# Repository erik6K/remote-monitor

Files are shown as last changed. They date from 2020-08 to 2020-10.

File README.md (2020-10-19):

# Repeater Monitor
## Background
An IoT device has been created to monitor the 240V AC normal supply, and 12V DC battery back-up supply for a radio repeater. Refer to the Project Design and Testing Document submitted along with this git repository for more information. The purpose of this git repository is to:
* Store the Arduino firmware backups for deploying new devices, or adding functionality
* Store relevent hardware manuals

To facilitate continuous deployment of the web application, it has been moved to a separate git repository. Updates to the web application should be made within this repository: [Repeater Monitor Web Application](https://github.com/tarrantja/remote-monitor-web). Updates made to the web application contained within this repository will not be deployed. 

## Authors
Created by:
* **Rio Akbar** (22507035)
* **Calvin Nguyen** (22509815)
* **Erik Stefan** (22224939)
* **James Tarrant** (20924309)
* **Dylan Turner** (22240231)

Developed for use in CITS3200, on behalf of SES CSU. 
[The full git repository can be found here.](https://github.com/tarrantja/remote-monitor-web)

## Licences
Hardware: CC BY-NC 3.0 AU

Firmware: GPLv3

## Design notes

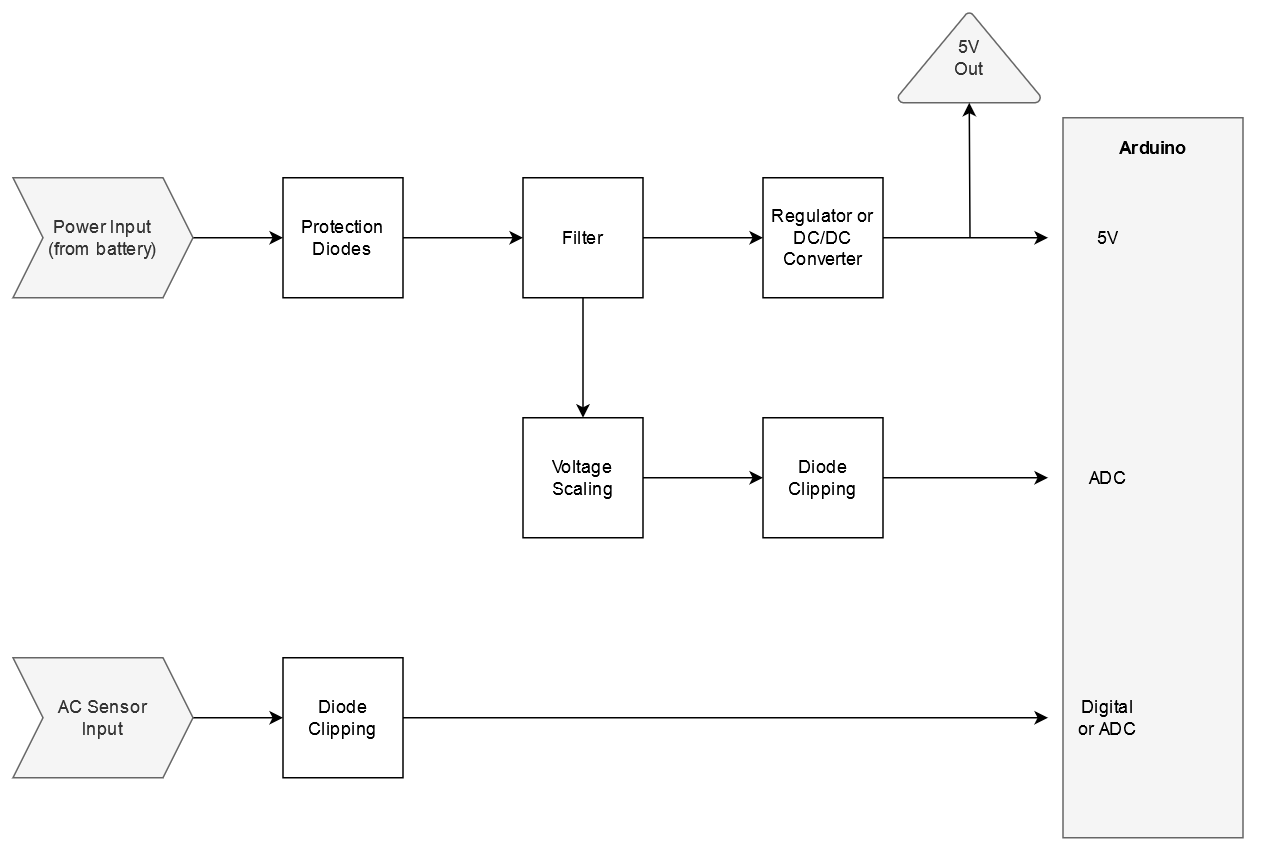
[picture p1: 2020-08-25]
hardware/Block Diagram.png

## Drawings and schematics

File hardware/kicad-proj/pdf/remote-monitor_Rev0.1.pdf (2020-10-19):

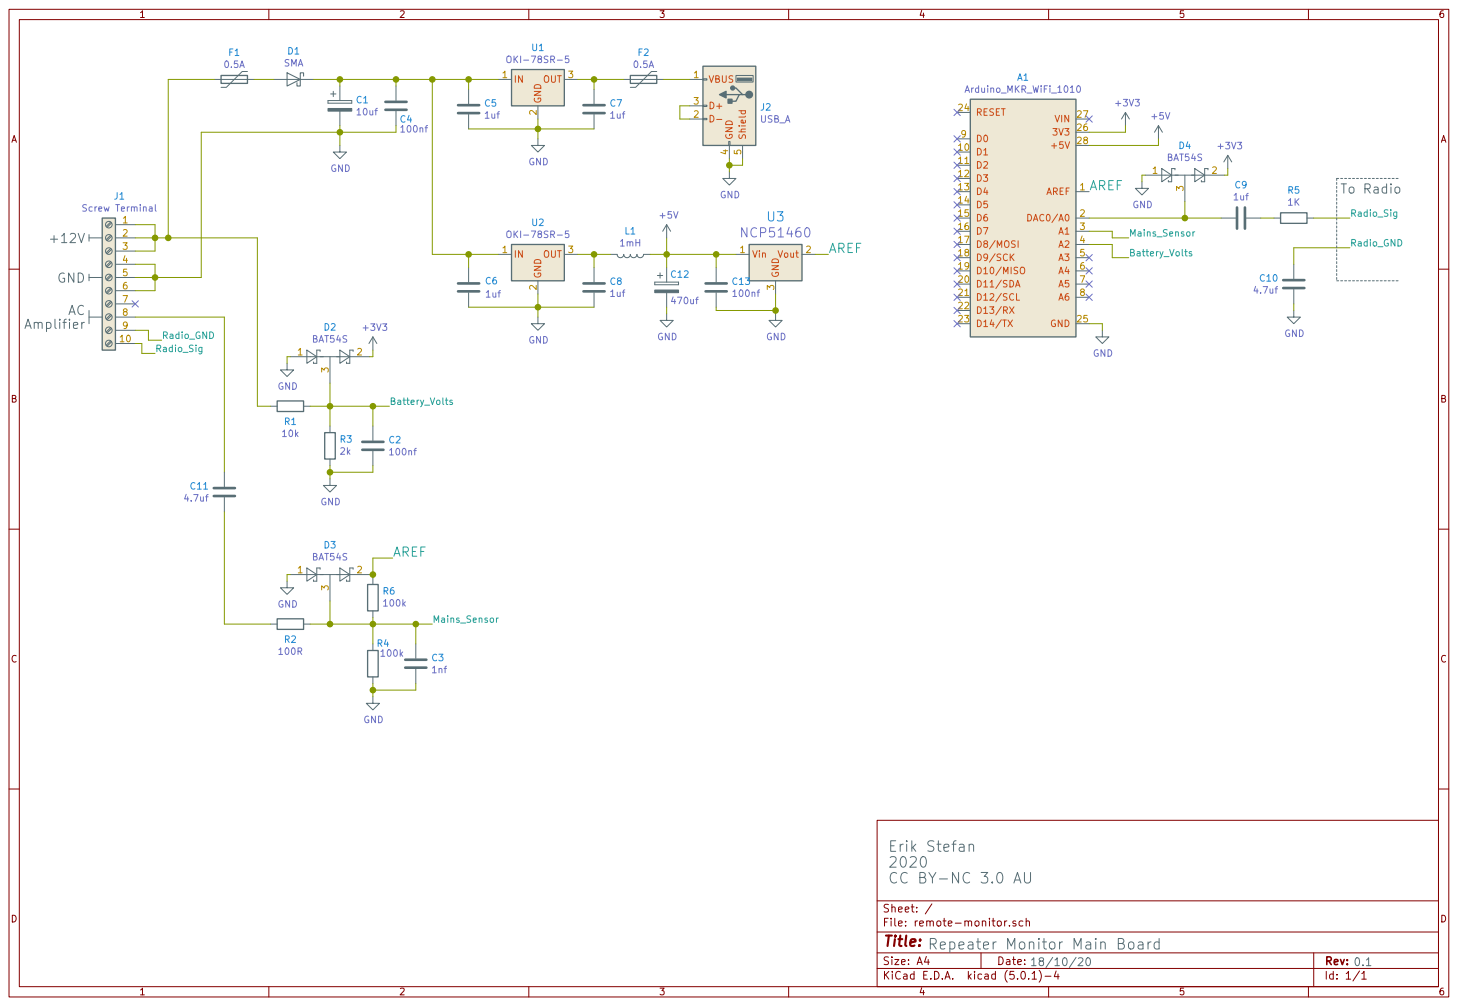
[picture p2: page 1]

Erik Stefan

Id: 1/1 Title: File: remote-monitor.sch Sheet: /
0.1 Repeater Monitor Main Board

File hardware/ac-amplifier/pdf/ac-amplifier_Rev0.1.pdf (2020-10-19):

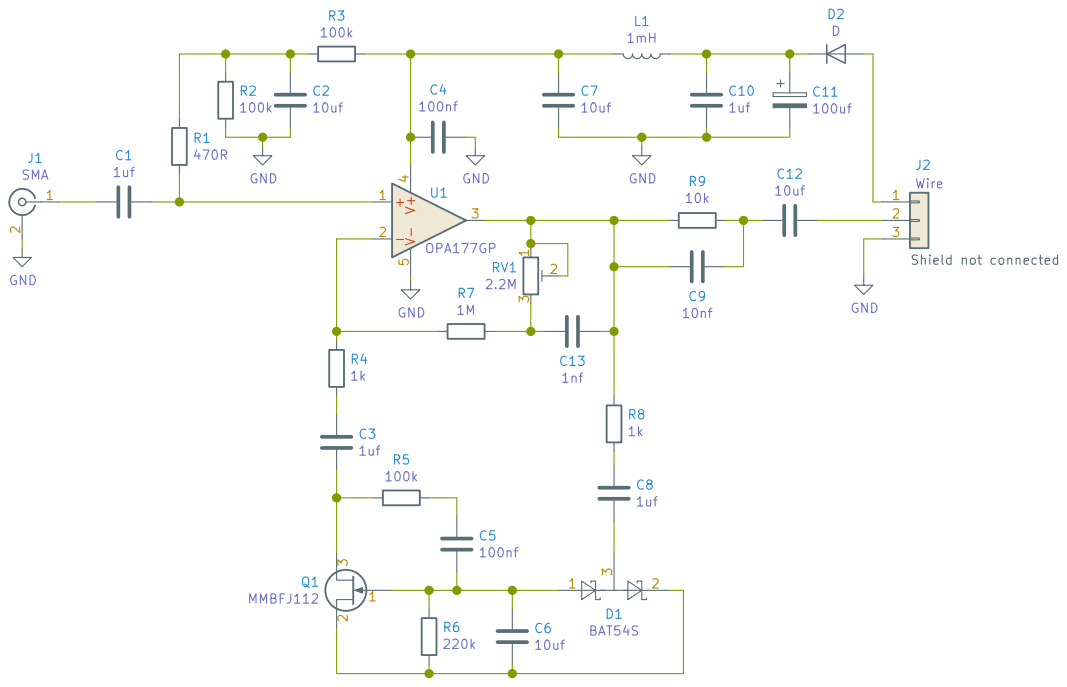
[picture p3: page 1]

Erik Stefan

File: ac-amplifier.sch Sheet: /
Id: 1/1 Title:
0.1 Repeater Monitor AC Amplifier

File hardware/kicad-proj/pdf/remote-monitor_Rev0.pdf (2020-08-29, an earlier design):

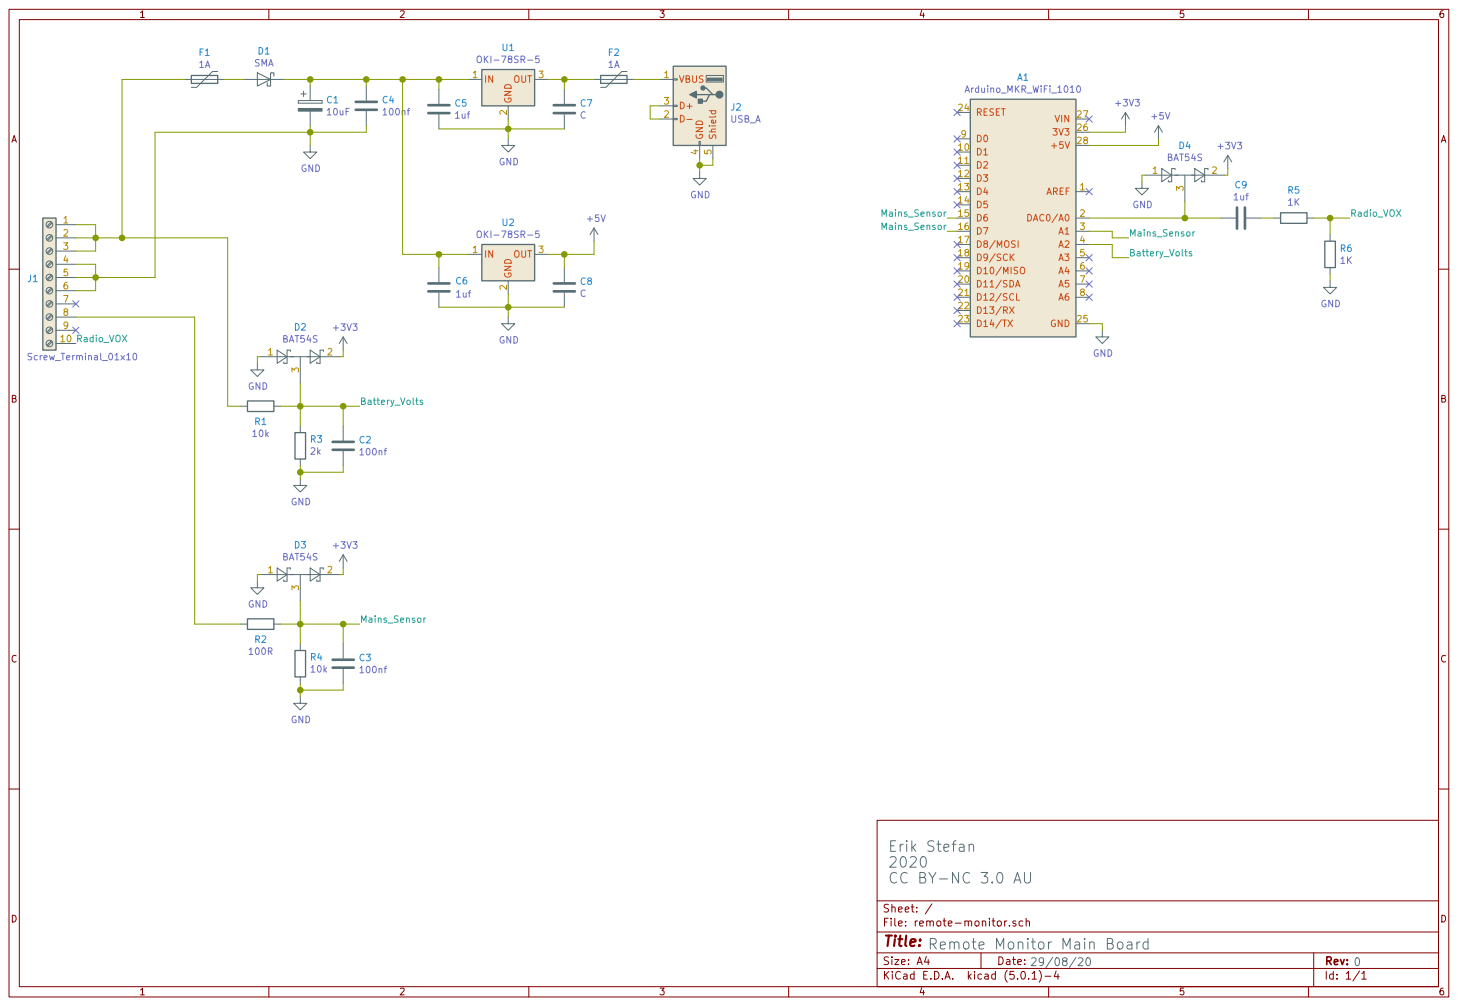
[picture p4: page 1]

Erik Stefan

Id: 1/1 Title: File: remote-monitor.sch Sheet: /
0 Remote Monitor Main Board

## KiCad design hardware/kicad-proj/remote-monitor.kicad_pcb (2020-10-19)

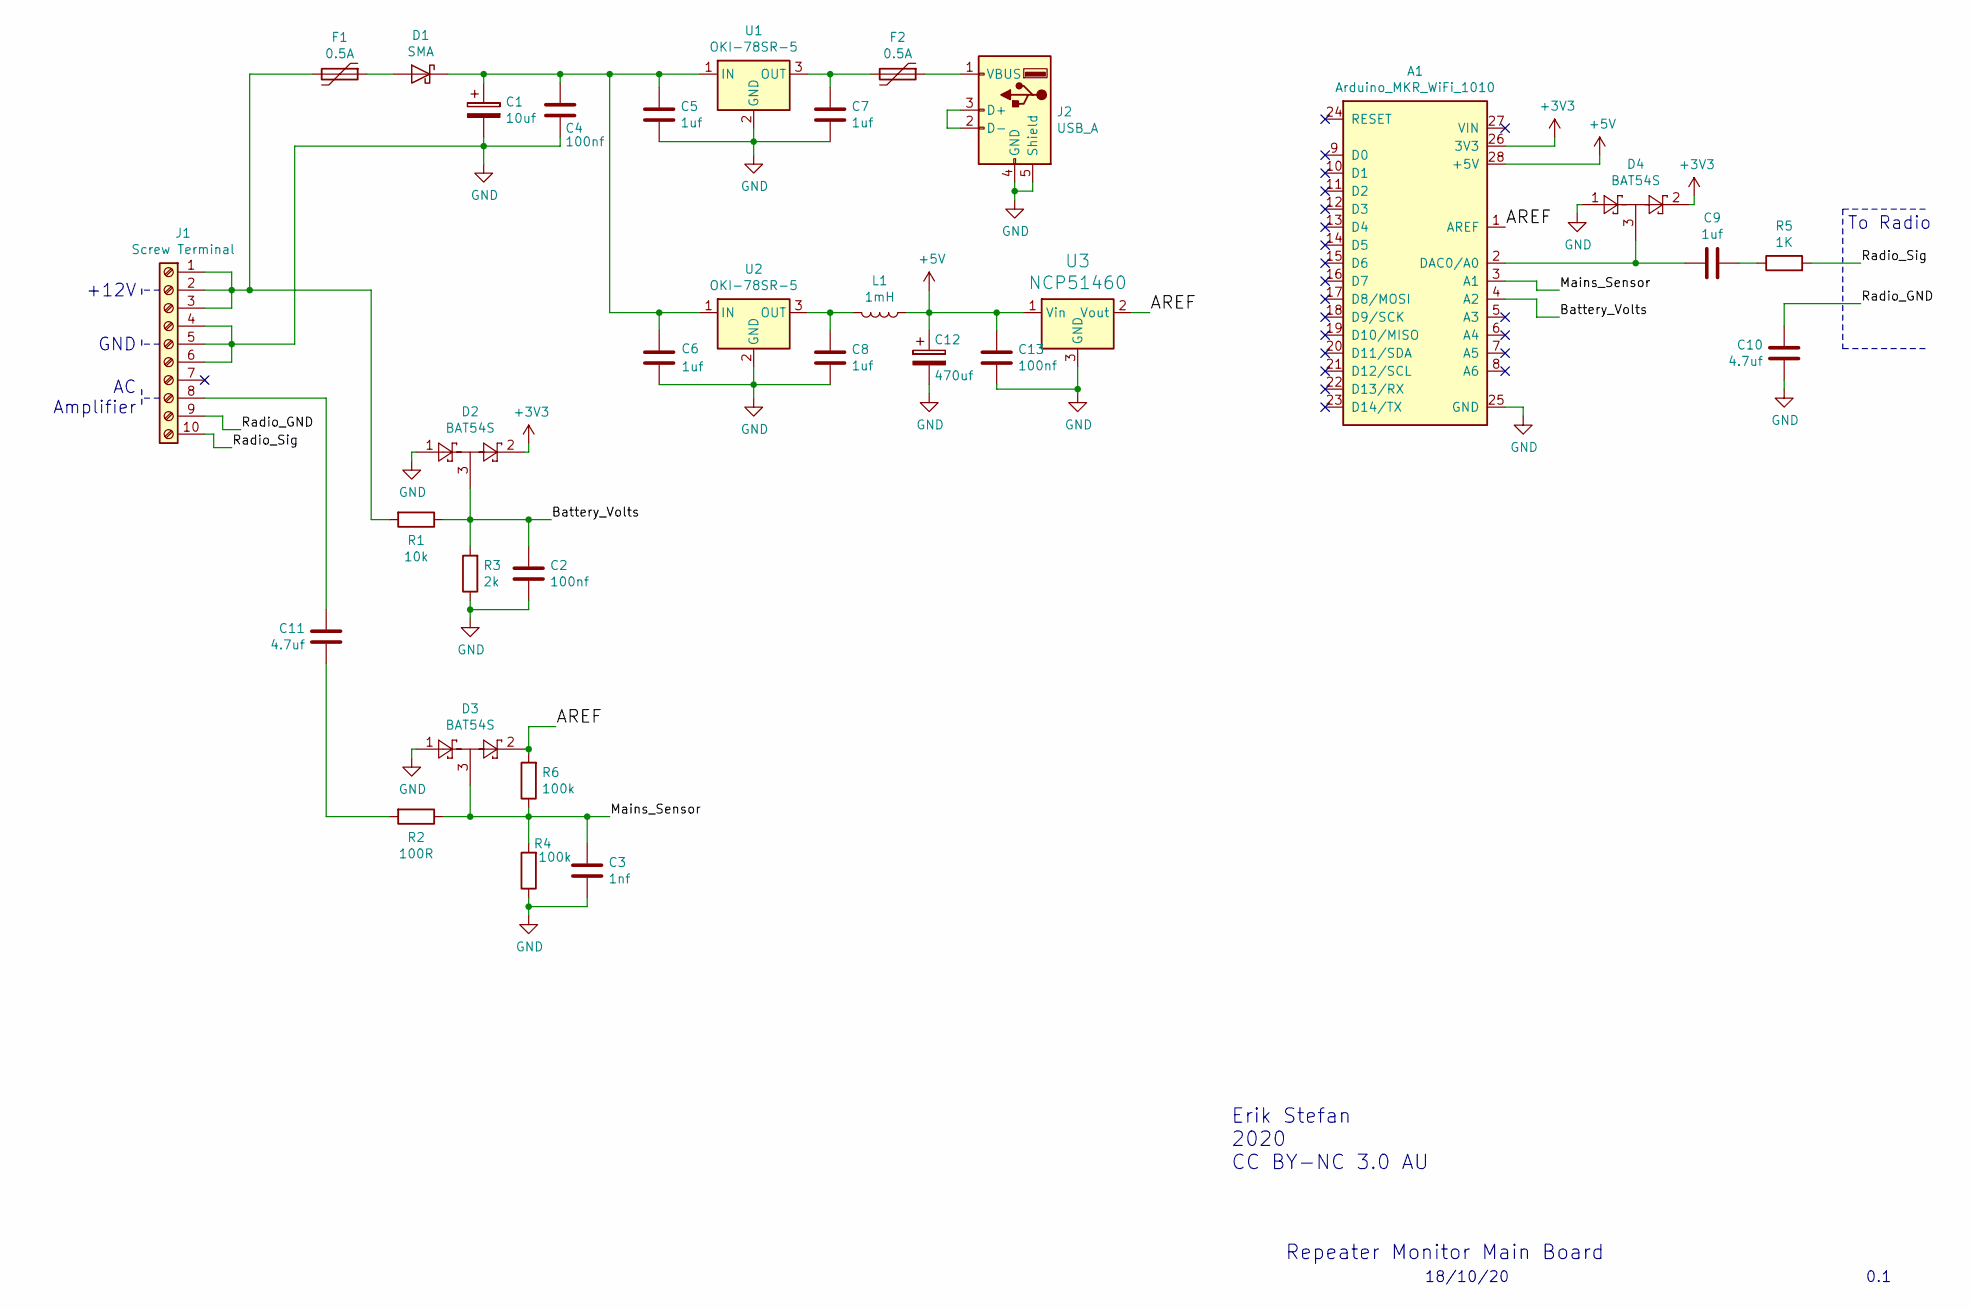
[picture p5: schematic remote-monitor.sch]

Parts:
A1: Arduino_MKR_WiFi_1010; Arduino_MKR_1010
C1: 10uf; CP_Elec_5x4.5
C2, C4, C13: 100nf; C_1206_3216Metric
C3: 1nf; C_1206_3216Metric
C5, C6, C7, C8, C9: 1uf; C_1206_3216Metric
C10, C11: 4.7uf; C_1206_3216Metric
C12: 470uf; CP_Elec_8x10.5
D1: SMA; D_SMA
D2, D3, D4: BAT54S; SOT-23
F1, F2: 0.5A; Fuse_1812_4532Metric
J1: Screw Terminal; Screw_Terminal_1x10
J2: USB_A; USB_A_Molex_105057_Vertical
L1: 1mH; L_6.3x6.3_H3
R1: 10k; R_1206_3216Metric
R2: 100R; R_1206_3216Metric
R3: 2k; R_1206_3216Metric
R4, R6: 100k; R_1206_3216Metric
R5: 1K; R_1206_3216Metric
U1, U2: OKI-78SR-5; Converter_DCDC_muRata_OKI-78SR_Vertical
U3: NCP51460; SOT-23

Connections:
+3V3: A1.26 (3V3), D2.2, D4.2
+5V: A1.28 (+5V), C12.1, C13.1, L1.1, U3.1 (Vin)
/AREF: A1.1 (AREF), D3.2, R6.2, U3.2 (Vout)
/Battery_Volts: A1.4 (A2), C2.1, D2.3, R1.1, R3.2
/Mains_Sensor: A1.3 (A1), C3.1, D3.3, R2.1, R4.2, R6.1
/Radio_GND: C10.1, J1.9
/Radio_Sig: J1.10, R5.2
GND: A1.25 (GND), C1.2, C2.2, C3.2, C4.2, C5.2, C6.2, C7.2, C8.2, C10.2, C12.2, C13.2, D2.1, D3.1, D4.1, J1.4, J1.5, J1.6, J2.4 (GND), J2.5 (Shield), R3.1, R4.1, U1.2 (GND), U2.2 (GND), U3.3 (GND)
unnamed: A1.2 (DAC0/A0), C9.2, D4.3
unnamed: C1.1, C4.1, C5.1, C6.1, D1.1 (K), U1.1 (IN), U2.1 (IN)
unnamed: C7.1, F2.2, U1.3 (OUT)
unnamed: C8.1, L1.2, U2.3 (OUT)
unnamed: C9.1, R5.1
unnamed: C11.1, J1.8
unnamed: C11.2, R2.2
unnamed: D1.2 (A), F1.1
unnamed: F1.2, J1.1, J1.2, J1.3, R1.2
unnamed: F2.1, J2.1 (VBUS)
unnamed: J2.2 (D-), J2.3 (D+)

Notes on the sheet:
0.1
Repeater Monitor Main Board
Erik Stefan 2020 CC BY-NC 3.0 AU
18/10/20
+12V
GND
AC Amplifier
To Radio

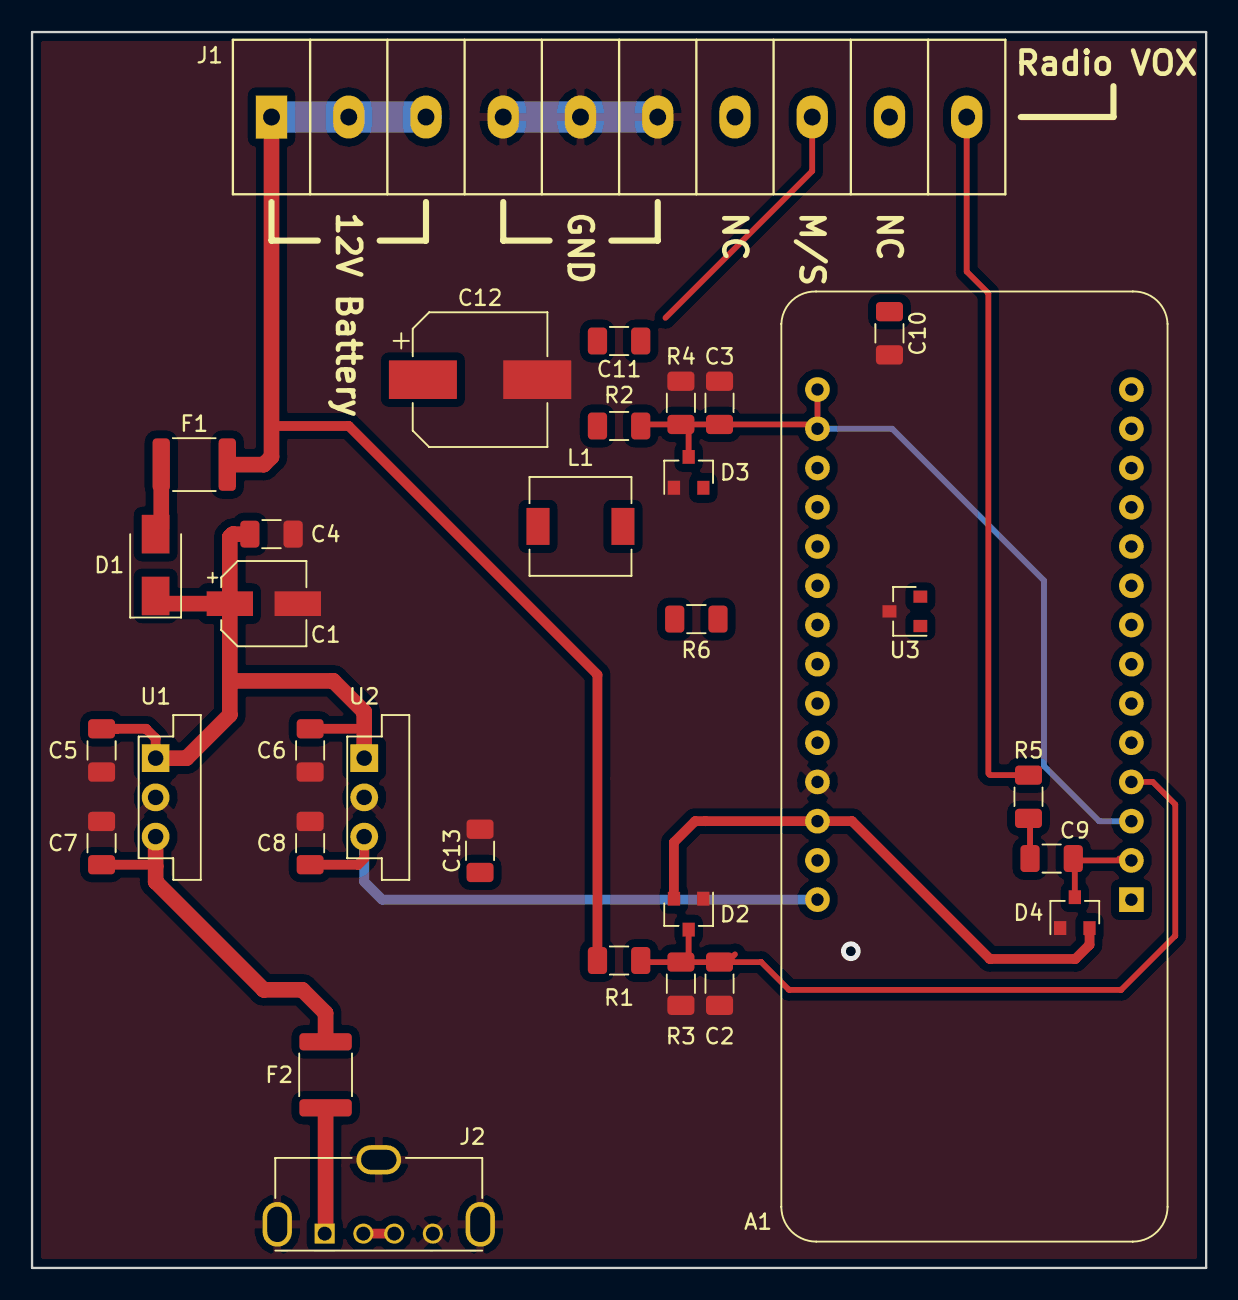
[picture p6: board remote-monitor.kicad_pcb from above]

Board: 2 copper layers, 76.0 x 80.0 mm, 32 parts (0 on the bottom side), 19 nets.

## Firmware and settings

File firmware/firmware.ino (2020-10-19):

#include <SPI.h>

#include "defs.h"
#include "reporter.h"
#include "monitor.h"


enum State { PERIODIC, ANALYSE };

volatile State global_STATE;
volatile bool flag_update = 0;


/* main timer initialisation */
void Init_Timer() {

	// generic clock (GCLK4) used to clock timers
	REG_GCLK_GENDIV =	GCLK_GENDIV_DIV(3) |	// divide the 48MHz clock source by divisor 3: 48MHz/3=16MHz
						GCLK_GENDIV_ID(4);		// configure Generic Clock (GCLK) 4
	while (GCLK->STATUS.bit.SYNCBUSY);			// wait for synchronization

	REG_GCLK_GENCTRL =	GCLK_GENCTRL_IDC |           // improved duty cycle for odd div
						GCLK_GENCTRL_GENEN |         // enable GCLK
						GCLK_GENCTRL_SRC_DFLL48M |   // 48MHz clock source
						GCLK_GENCTRL_ID(4);          // configure GCLK4
	while (GCLK->STATUS.bit.SYNCBUSY);

	REG_GCLK_CLKCTRL =	GCLK_CLKCTRL_CLKEN |		// enable GCLK4
						GCLK_CLKCTRL_GEN_GCLK4 |	// select GCLK4
						GCLK_CLKCTRL_ID_TC4_TC5;	// GCLK4 to TC4 and TC5
	while (GCLK->STATUS.bit.SYNCBUSY);

	// timer setup
	REG_TC4_INTFLAG |= TC_INTFLAG_MC1 | TC_INTFLAG_MC0 | TC_INTFLAG_OVF;	// Clear the interrupt flags
	REG_TC4_INTENSET = TC_INTENSET_OVF;										// Enable TC4 interrupts

	REG_TC4_CTRLA |=	TC_CTRLA_PRESCALER_DIV64 |
						TC_CTRLA_ENABLE;			// Enable TC4
	while (TC4->COUNT16.STATUS.bit.SYNCBUSY);

	NVIC_EnableIRQ(TC4_IRQn);         // Connect TC4 to Nested Vector Interrupt Controller (NVIC)
}

void setup() {

	// for debugging purposes
	/*SerialUSB.begin(9600);
	while (!SerialUSB) {
	// wait for serial port to connect
	}*/
 	
 	// init connection to azure IoT hub / radio only mode
	reporter.Init();

	// init peripherals for monitoring battery and mains
	monitor.Init();

	// initialise timer
	Init_Timer();

	// enter battery sampling state
	global_STATE = PERIODIC;
}

void loop() {
	static int report_counter = 0;

	// give the MQTT handler time to do its thing - does nothing if RADIO_ONLY
	reporter.mqtt_loop();

	switch(global_STATE)
	{
		case PERIODIC:

			if (flag_update) {
				flag_update = false;

				monitor.take_battery_sample();

				//SerialUSB.print("Vb: "); // debugging
				//SerialUSB.println(monitor.get_latest_battery_volts());
			}

			break;

		case ANALYSE:

			monitor.take_mains_samples();
			while(monitor.adc_busy()); // wait for samples to be taken

			/*
			// dump mains samples
			for (int i=0; i<SAMPLES; i++) {
			SerialUSB.print(i);
			SerialUSB.print(',');
			SerialUSB.println(monitor.get_mains_sample(i));
			}*/

			monitor.remove_DC();
			monitor.compute_fft();

			monitor.verify_50Hz();

			//SerialUSB.print("50Hz: "); // debugging
			//SerialUSB.println(monitor.get_latest_mains_status() ? "ON" : "OFF");

			monitor.save_min_battery();

			// after 10 mains checks we report data to web
			report_counter++;
			if (report_counter >= NUM_CYCLES_B4_REPORT) {
				report_counter = 0;
				reporter.report_data(monitor.get_mains_status(), monitor.get_battery_volts());
			}
			
			global_STATE = PERIODIC;
			ENABLE_TIMER()

			break;

		default:
			// should never end up here - restart system
			NVIC_SystemReset();
			break;
	}
}

/* ------Interrupt Service Routines------ */

void TC4_Handler() {	// ISR for timer TC4
	static uint8_t counter = 0;

	// check for overflow (OVF) interrupt
	if (TC4->COUNT8.INTFLAG.bit.OVF && TC4->COUNT8.INTENSET.bit.OVF) {

		// sample battery voltage 10 times before state change
		if (counter < NUM_BATT_SAMPLES) {

	   		flag_update = true;
	   		counter++;
	   	}
	   	else {
	   		counter = 0;
	   		global_STATE = ANALYSE;
	   		DISABLE_TIMER()
	   	}
      

	REG_TC4_INTFLAG = TC_INTFLAG_OVF;	// clear the overflow interrupt flag
	}

}

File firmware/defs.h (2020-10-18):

#ifndef DEFS_H
#define DEFS_H


#define RADIO_VOX_PIN 15

/* 
NUM_CYCLES defines how many times the ANALYSE state is entered before data is
reported. It controls the frequency of messages sent to Azure, and the size of
the mains_status and battery_min_values array which are averaged before sending.
Each cycle takes roughly ~4 secs.
*/
#define NUM_CYCLES_B4_REPORT 20
#define NUM_BATT_SAMPLES 10

/*
Factor for scaling 12 bit ADC reading to actual voltage, 1240.91 scales the 12
bit reading to 0-3.3V, the numerator is determined by the voltage divider in
front of the input pin A2.
*/
#define BATT_SCALING_FACTOR (6.4 / 1240.91)



#define DISABLE_TIMER()	REG_TC4_CTRLA &= ~TC_CTRLA_ENABLE; \
						while (TC4->COUNT16.STATUS.bit.SYNCBUSY);

#define ENABLE_TIMER() 	REG_TC4_CTRLA |= TC_CTRLA_ENABLE; \
						while (TC4->COUNT16.STATUS.bit.SYNCBUSY);

#define DISABLE_ADC()	REG_ADC_CTRLA &= ~ADC_CTRLA_ENABLE; \
						while (ADC->STATUS.bit.SYNCBUSY);

#define ENABLE_ADC()	REG_ADC_CTRLA |= ADC_CTRLA_ENABLE; \
						while (ADC->STATUS.bit.SYNCBUSY);

#endif

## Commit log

2020-08-25 added .gitignore for kiCAD
2020-08-25 initial kicad setup and block diagram
    [remote-monitor.kicad_pcb, remote-monitor.sch]
2020-08-28 power supply
    [remote-monitor.sch]
2020-08-29 prototype main board complete
    [remote-monitor-B.Cu.gbr, remote-monitor-B.Mask.gbr, remote-monitor-B.Paste.gbr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]
2020-08-30 updated pcb dimensions and mounting holes for different enclosure
    [remote-monitor-B.Cu.gbr, remote-monitor-B.Mask.gbr, remote-monitor-B.Paste.gbr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]
2020-08-31 fix error in monitor.cpp
    [monitor.cpp]
2020-09-03 added timer
2020-09-03 Firmware update for mains sensor
2020-09-04 compact digital filter
2020-09-08 fix styling for different devices
2020-09-08 Firmware digital filter tweak
2020-10-01 freerun adc working
2020-10-02 clean-up and added state machine for swapping ADC between battery and mains sensing
    [firmware.ino, monitor.cpp]
2020-10-04 adc can now swap between battery and mains sampling
    [defs.h, firmware.ino, monitor.cpp]
2020-10-14 rgb led notification
2020-10-14 testing interrupt disables
2020-10-16 testing GCLK settings causing issues
    [firmware.ino, reporter.cpp]
2020-10-18 Reporting of float value for battery
2020-10-18 LED notification, general cleanup, improved battery monitoring
2020-10-19 updated hardware designs
    [ac-amplifier.kicad_pcb, ac-amplifier.sch, remote-monitor.kicad_pcb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]
